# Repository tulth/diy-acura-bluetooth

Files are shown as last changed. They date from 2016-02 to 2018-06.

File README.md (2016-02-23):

# diy-acura-bluetooth
Overview
====================
My DIY project to understand, communicate, and add bluetooth with a 1999 Acura RL bose head unit

Cloning
====================
Be sure to include 

    --recursive 
  
during the git clone to get the submodules!

If you missed this, and do not want to reclone, do the following:

    git submodule update --init --recursive

Building
====================
Build platform:
Arch linux 
with community package: arm-none-eabi-gcc 5.3.0-1
with community package: arm-none-eabi-newlib
with package: python

Desktop shared library
------------
    cd target_desktop
    ./make.sh

Teensy3 embedded executables
------------
    cd target_teensy3
    ./make.sh

Loading
====================
To load you will need this arch linux AUR: teensy-loader-cli

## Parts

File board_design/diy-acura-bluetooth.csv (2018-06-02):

Reference | Value | Footprint | Datasheet | MFN | MFP
P1 | MBUS_CONN | diy-acura-bluetooth:mbus_conn |  | Sullins | PRPC040SBAN-M71RC
P2 | CONN_01X03 | Pin_Headers:Pin_Header_Straight_1x03 |  | Sullins | PRPC040SAAN-RC
U1 | TLV2362 | Housings_DIP:DIP-8_W7.62mm_LongPads |  | Texas Instruments | TLV2362IP
R2 | 100K | Resistors_ThroughHole:Resistor_Horizontal_RM10mm |  | Yageo | MFR-25FBF52-100K
R1 | 100K | Resistors_ThroughHole:Resistor_Horizontal_RM10mm |  | Yageo | MFR-25FBF52-100K
R7 | 20K | Resistors_ThroughHole:Resistor_Horizontal_RM10mm |  | Yageo | MFR-25FBF52-20K
R8 | 20K | Resistors_ThroughHole:Resistor_Horizontal_RM10mm |  | Yageo | MFR-25FBF52-20K
R3 | 20K | Resistors_ThroughHole:Resistor_Horizontal_RM10mm |  | Yageo | MFR-25FBF52-20K
R4 | 20K | Resistors_ThroughHole:Resistor_Horizontal_RM10mm |  | Yageo | MFR-25FBF52-20K
C2 | 1uF | Capacitors_ThroughHole:C_Rect_L7.5_W6.5_P5 |  | Kemet | R82DC4100AA60K
C1 | 1uF | Capacitors_ThroughHole:C_Rect_L7.5_W6.5_P5 |  | Kemet | R82DC4100AA60K
C5 | 1uF | Capacitors_ThroughHole:C_Rect_L7.5_W6.5_P5 |  | Kemet | R82DC4100AA60K
R9 | 20K | Resistors_ThroughHole:Resistor_Horizontal_RM10mm |  | Yageo | MFR-25FBF52-20K
R5 | 20K | Resistors_ThroughHole:Resistor_Horizontal_RM10mm |  | Yageo | MFR-25FBF52-20K
R6 | 20K | Resistors_ThroughHole:Resistor_Horizontal_RM10mm |  | Yageo | MFR-25FBF52-20K
C4 | 1uF | Capacitors_ThroughHole:C_Rect_L7.5_W6.5_P5 |  | Kemet | R82DC4100AA60K
C3 | 1uF | Capacitors_ThroughHole:C_Rect_L7.5_W6.5_P5 |  | Kemet | R82DC4100AA60K
R10 | 20K | Resistors_ThroughHole:Resistor_Horizontal_RM10mm |  | Yageo | MFR-25FBF52-20K
C9 | 10uF | Capacitors_ThroughHole:C_Radial_D5_L11_P2 |  | Kemet | ESK106M016AC3AA
C10 | 0.1uF | Capacitors_ThroughHole:C_Disc_D6_P5 |  | Vishay | K104K10X7RF5UH5
C7 | 2.7uF | Capacitors_ThroughHole:C_Rect_L27_W9_H17_P23 |  | Panasonic | ECW-FD2W275K
C6 | 2.7uF | Capacitors_ThroughHole:C_Rect_L27_W9_H17_P23 |  | Panasonic | ECW-FD2W275K
U3 | R-78E5.0-0.5 | diy-acura-bluetooth:R-78E5.0-0.5 |  | Recom | R-78E5.0-0.5
D1 | 1N4004 | Diodes_ThroughHole:Diode_DO-41_SOD81_Horizontal_RM10 |  | Diodes Incorporated | 1N4004
Q1 | 2N3904 | TO_SOT_Packages_THT:TO-92_Molded_Wide_Oval |  | On Semiconductor | 2N3904
R11 | 4.75K | Resistors_ThroughHole:Resistor_Horizontal_RM10mm |  | Yageo | MFR-25FBF52-4K75
Q3 | 2N3904 | TO_SOT_Packages_THT:TO-92_Molded_Wide_Oval |  | On Semiconductor | 2N3904
R14 | 4.75K | Resistors_ThroughHole:Resistor_Horizontal_RM10mm |  | Yageo | MFR-25FBF52-4K75
C11 | 100uF/10V | Capacitors_ThroughHole:C_Radial_D5_L11_P2 |  | Panasonic | ECA-1AM101
U2 | AS393P-E1 | Housings_DIP:DIP-8_W7.62mm_LongPads |  | Diodes Incorporated | AS393P-E1
R13 | 47.5K | Resistors_ThroughHole:Resistor_Horizontal_RM10mm |  | Yageo | MFR-25FBF52-47K5
R15 | 47.5K | Resistors_ThroughHole:Resistor_Horizontal_RM10mm |  | Yageo | MFR-25FBF52-47K5
R12 | 20K | Resistors_ThroughHole:Resistor_Horizontal_RM10mm |  | Yageo | MFR-25FBF52-20K
Q2 | IRFU9024NPBF | diy-acura-bluetooth:TO-251AA-TPAD |  | International Rectifier | IRFU9024NPBF
Q4 | 2N3904 | TO_SOT_Packages_THT:TO-92_Molded_Wide_Oval |  | On Semiconductor | 2N3904
R17 | 47.5K | Resistors_ThroughHole:Resistor_Horizontal_RM10mm |  | Yageo | MFR-25FBF52-47K5
R18 | 47.5K | Resistors_ThroughHole:Resistor_Horizontal_RM10mm |  | Yageo | MFR-25FBF52-47K5
R16 | 47.5K | Resistors_ThroughHole:Resistor_Horizontal_RM10mm |  | Yageo | MFR-25FBF52-47K5
U4 | TEENSY-3.2 | diy-acura-bluetooth:Teensy-3.1 |  | Sparkfun | DEV-13736
U5 | RN-52-BREAKOUT | diy-acura-bluetooth:RN-52-BREAKOUT |  | Sparkfun | WRL-12849

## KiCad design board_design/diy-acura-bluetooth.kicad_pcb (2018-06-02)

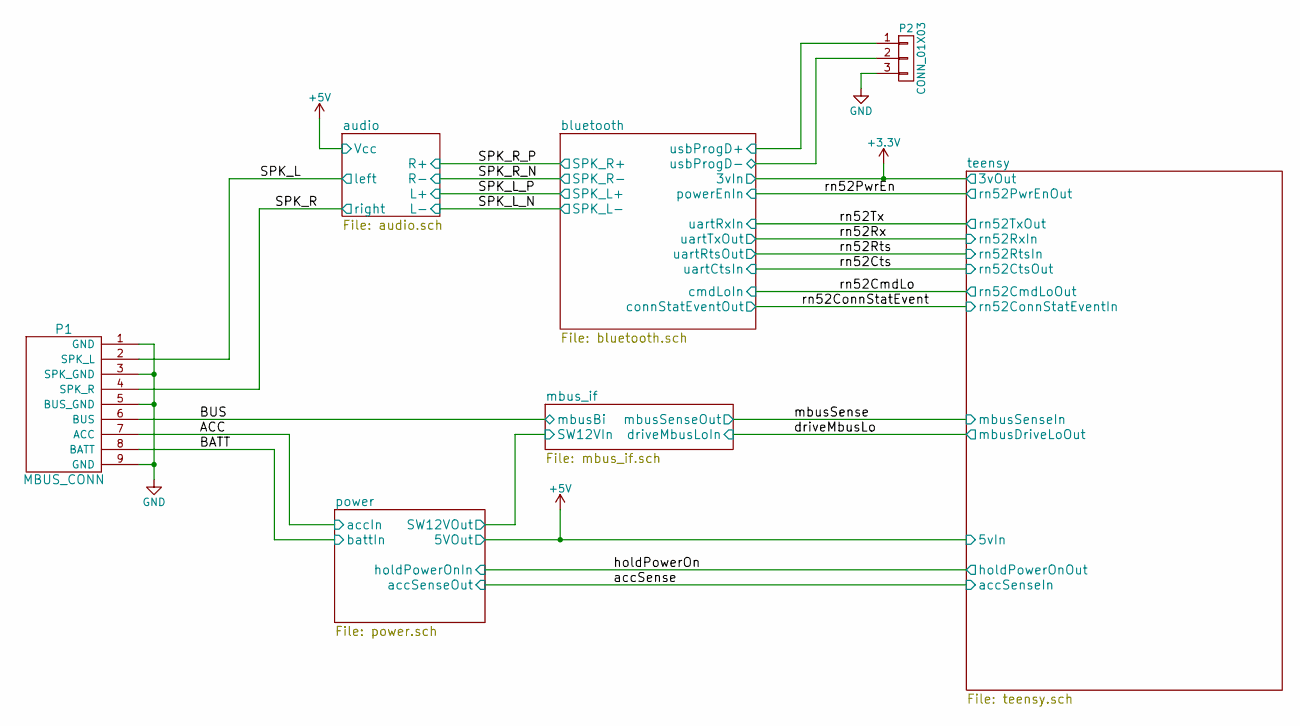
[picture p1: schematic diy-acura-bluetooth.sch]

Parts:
P1: MBUS_CONN; mbus_conn
P2: CONN_01X03; Pin_Header_Straight_1x03

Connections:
/audio/left: P1.2 (SPK_L); also elsewhere on the board
/audio/right: P1.4 (SPK_R); also elsewhere on the board
/bluetooth/usbProgD+: P2.1; also elsewhere on the board
/bluetooth/usbProgD-: P2.2; also elsewhere on the board
/mbus_if/mbusBi: P1.6 (BUS); also elsewhere on the board
/power/accIn: P1.7 (ACC); also elsewhere on the board
/power/battIn: P1.8 (BATT); also elsewhere on the board
GND: P1.1 (GND), P1.3 (SPK_GND), P1.5 (BUS_GND), P1.9 (GND), P2.3; also elsewhere on the board

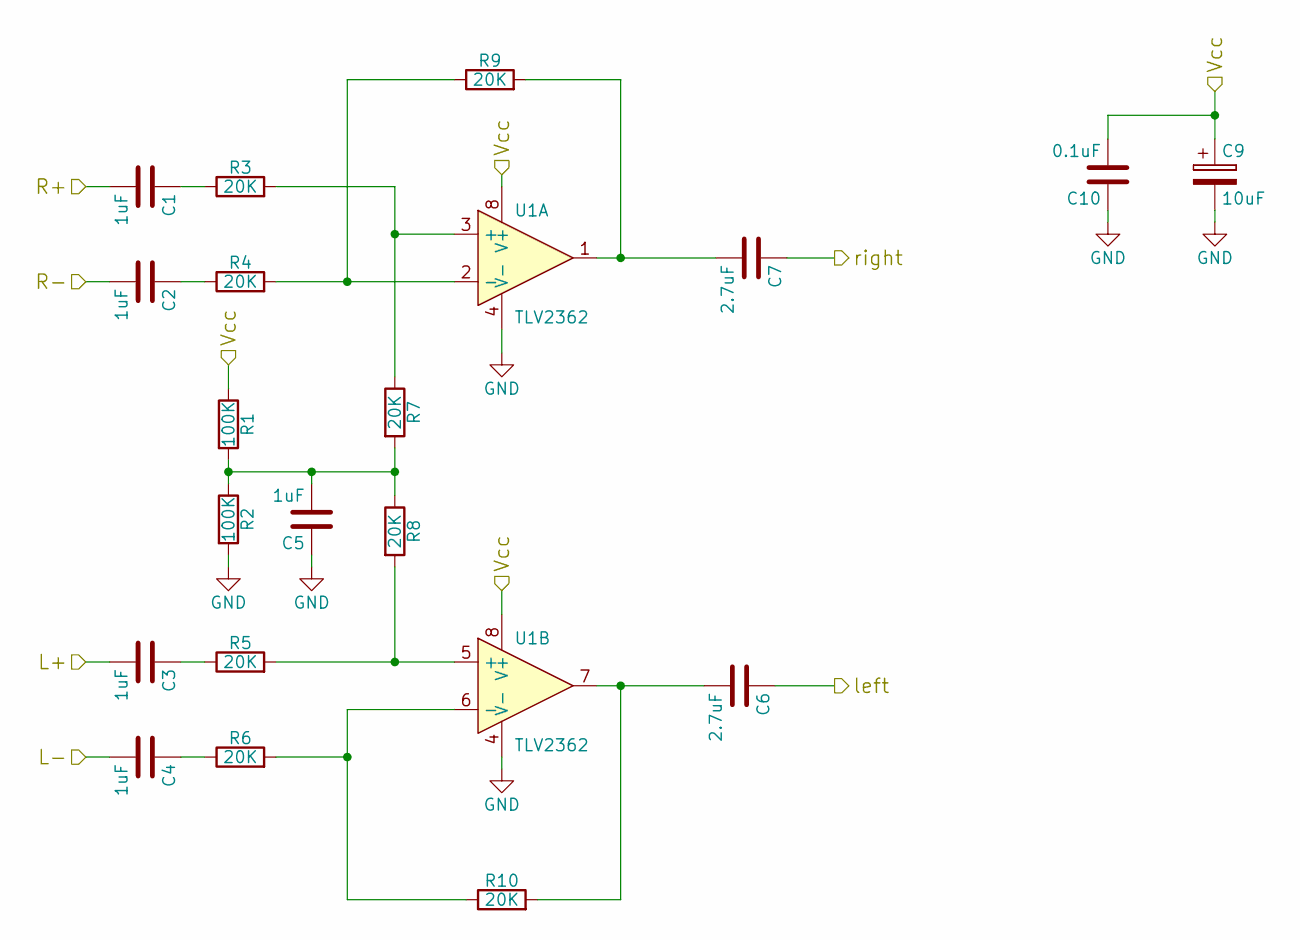
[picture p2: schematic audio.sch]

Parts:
C1, C2, C3, C4, C5: 1uF; C_Rect_L7.5_W6.5_P5
C6, C7: 2.7uF; C_Rect_L27_W9_H17_P23
C9: 10uF; C_Radial_D5_L11_P2
C10: 0.1uF; C_Disc_D6_P5
R1, R2: 100K; Resistor_Horizontal_RM10mm
R3, R4, R5, R6, R7, R8, R9, R10: 20K; Resistor_Horizontal_RM10mm
U1: TLV2362; DIP-8_W7.62mm_LongPads

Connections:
+5V: C9.1, C10.2, R1.1, U1.8 (V+); also elsewhere on the board
/audio/L+: C3.2; also elsewhere on the board
/audio/L-: C4.2; also elsewhere on the board
/audio/R+: C1.2; also elsewhere on the board
/audio/R-: C2.2; also elsewhere on the board
/audio/left: C6.1; also elsewhere on the board
/audio/right: C7.1; also elsewhere on the board
GND: C5.1, C9.2, C10.1, R2.2, U1.4 (V-); also elsewhere on the board
unnamed: C1.1, R3.1
unnamed: C2.1, R4.1
unnamed: C3.1, R5.1
unnamed: C4.1, R6.1
unnamed: C5.2, R1.2, R2.1, R7.2, R8.1
unnamed: C6.2, R10.2, U1.7
unnamed: C7.2, R9.2, U1.1
unnamed: R3.2, R7.1, U1.3 (+)
unnamed: R4.2, R9.1, U1.2 (-)
unnamed: R5.2, R8.2, U1.5 (+)
unnamed: R6.2, R10.1, U1.6 (-)

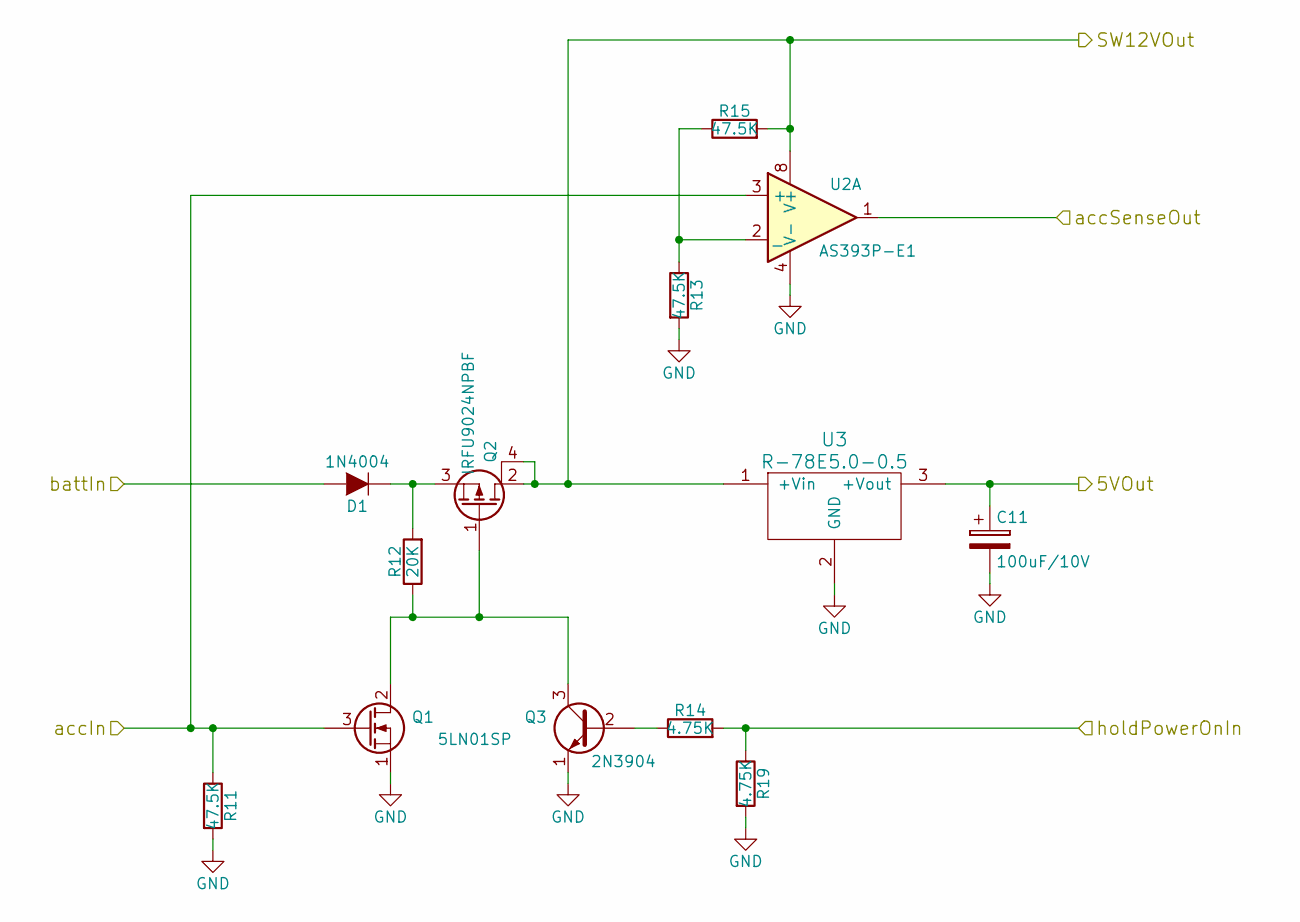
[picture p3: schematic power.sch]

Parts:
C11: 100uF/10V; C_Radial_D5_L11_P2
D1: 1N4004; Diode_DO-41_SOD81_Horizontal_RM10
Q1: 5LN01SP; TO-92_Molded_Wide_Oval
Q2: IRFU9024NPBF; TO-251AA-TPAD
Q3: 2N3904; TO-92_Molded_Wide_Oval
R11, R13, R15: 47.5K; Resistor_Horizontal_RM10mm
R12: 20K; Resistor_Horizontal_RM10mm
R14, R19: 4.75K; Resistor_Horizontal_RM10mm
U2: AS393P-E1; DIP-8_W7.62mm_LongPads
U3: R-78E5.0-0.5

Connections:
+5V: C11.1, U3.3 (+Vout); also elsewhere on the board
/mbus_if/SW12VIn: Q2.2 (D), Q2.4 (D), R15.2, U2.8 (V+), U3.1 (+Vin); also elsewhere on the board
/power/accIn: Q1.3 (G), R11.1, U2.3 (+); also elsewhere on the board
/power/battIn: D1.2 (A); also elsewhere on the board
/power/holdPowerOnIn: R14.2, R19.1; also elsewhere on the board
/teensy/accSenseIn: U2.1; also elsewhere on the board
GND: C11.2, Q1.1 (S), Q3.1 (E), R11.2, R13.2, R19.2, U2.4 (V-), U3.2 (GND); also elsewhere on the board
unnamed: D1.1 (K), Q2.3 (S), R12.2
unnamed: Q1.2 (D), Q2.1 (G), Q3.3 (C), R12.1
unnamed: Q3.2 (B), R14.1
unnamed: R13.1, R15.1, U2.2 (_)

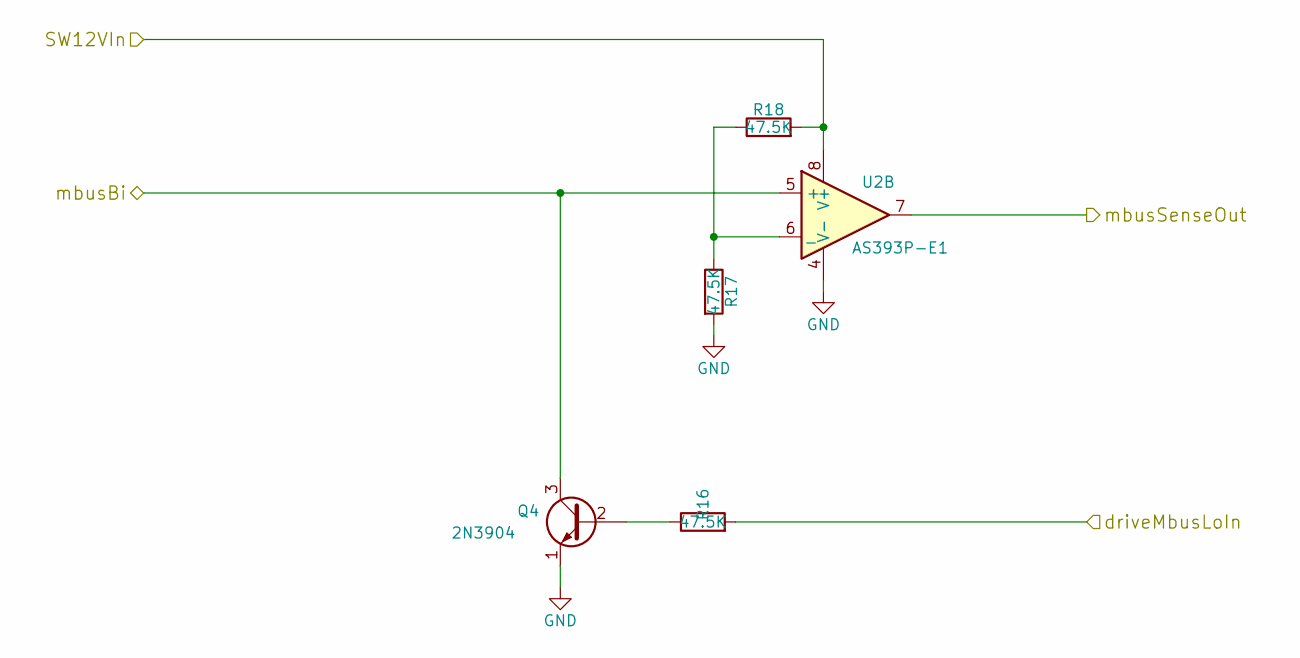
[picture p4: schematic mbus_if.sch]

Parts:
Q4: 2N3904; TO-92_Molded_Wide_Oval
R16, R17, R18: 47.5K; Resistor_Horizontal_RM10mm
U2: AS393P-E1; DIP-8_W7.62mm_LongPads

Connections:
/mbus_if/SW12VIn: R18.2, U2.8 (V+); also elsewhere on the board
/mbus_if/driveMbusLoIn: R16.2; also elsewhere on the board
/mbus_if/mbusBi: Q4.3 (C), U2.5 (+); also elsewhere on the board
/teensy/mbusSenseIn: U2.7; also elsewhere on the board
GND: Q4.1 (E), R17.2, U2.4 (V-); also elsewhere on the board
unnamed: Q4.2 (B), R16.1
unnamed: R17.1, R18.1, U2.6 (_)

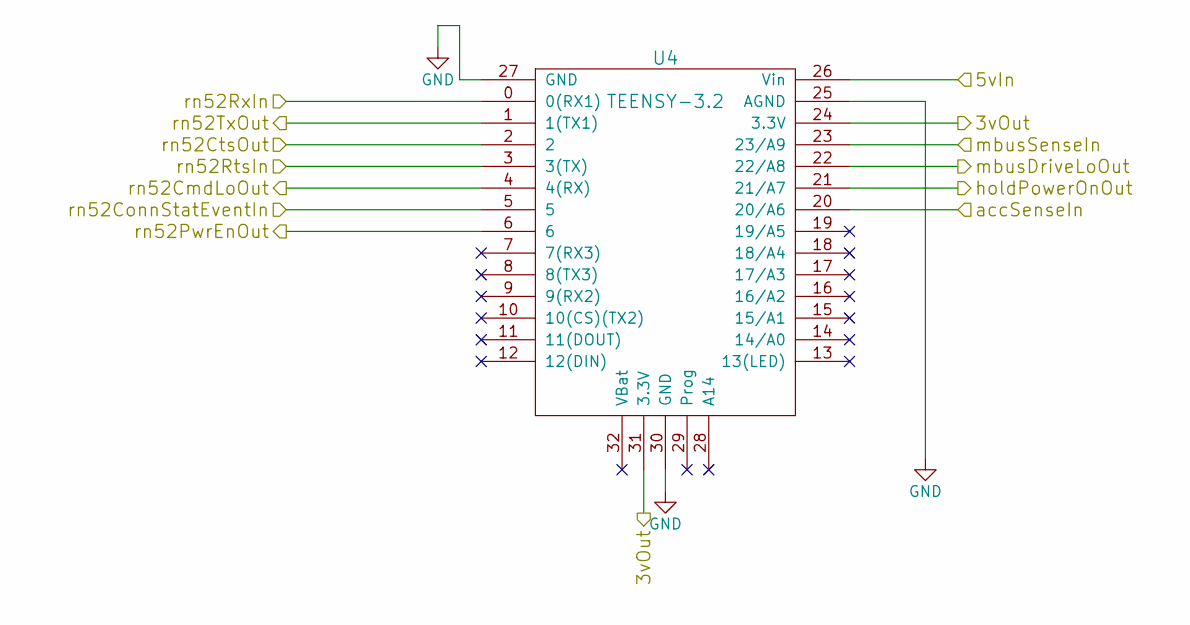
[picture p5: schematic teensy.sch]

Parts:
U4: TEENSY-3.2; Teensy-3.1

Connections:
+3V3: U4.24 (3.3V), U4.31 (3.3V); also elsewhere on the board
+5V: U4.26 (Vin); also elsewhere on the board
/bluetooth/cmdLoIn: U4.4 (4(RX)); also elsewhere on the board
/bluetooth/connStatEventOut: U4.5; also elsewhere on the board
/bluetooth/powerEnIn: U4.6; also elsewhere on the board
/mbus_if/driveMbusLoIn: U4.22 (22/A8); also elsewhere on the board
/power/holdPowerOnIn: U4.21 (21/A7); also elsewhere on the board
/teensy/accSenseIn: U4.20 (20/A6); also elsewhere on the board
/teensy/mbusSenseIn: U4.23 (23/A9); also elsewhere on the board
/teensy/rn52CtsOut: U4.2; also elsewhere on the board
/teensy/rn52RtsIn: U4.3 (3(TX)); also elsewhere on the board
/teensy/rn52RxIn: U4.0 (0(RX1)); also elsewhere on the board
/teensy/rn52TxOut: U4.1 (1(TX1)); also elsewhere on the board
GND: U4.25 (AGND), U4.27 (GND), U4.30 (GND); also elsewhere on the board

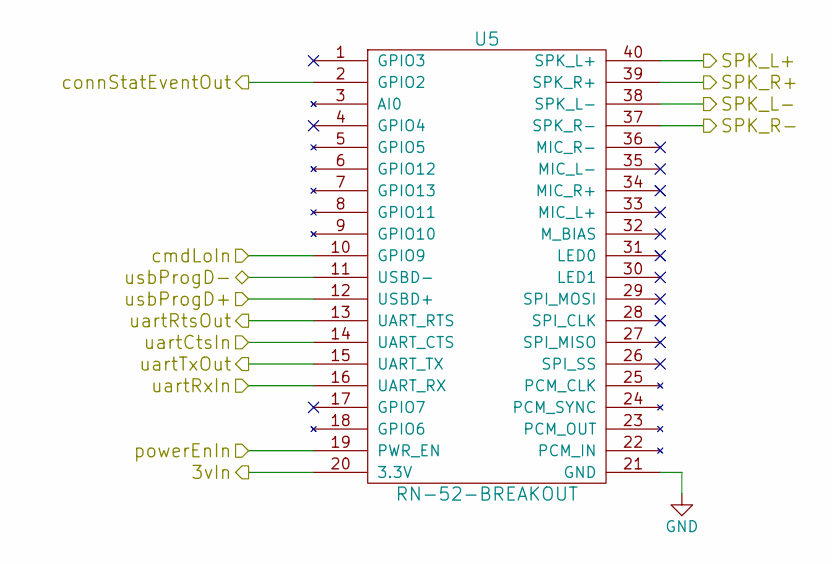
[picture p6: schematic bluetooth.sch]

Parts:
U5: RN-52-BREAKOUT

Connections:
+3V3: U5.20 (3.3V); also elsewhere on the board
/audio/L+: U5.40 (SPK_L+); also elsewhere on the board
/audio/L-: U5.38 (SPK_L-); also elsewhere on the board
/audio/R+: U5.39 (SPK_R+); also elsewhere on the board
/audio/R-: U5.37 (SPK_R-); also elsewhere on the board
/bluetooth/cmdLoIn: U5.10 (GPIO9); also elsewhere on the board
/bluetooth/connStatEventOut: U5.2 (GPIO2); also elsewhere on the board
/bluetooth/powerEnIn: U5.19 (PWR_EN); also elsewhere on the board
/bluetooth/usbProgD+: U5.12 (USBD+); also elsewhere on the board
/bluetooth/usbProgD-: U5.11 (USBD-); also elsewhere on the board
/teensy/rn52CtsOut: U5.14 (UART_CTS); also elsewhere on the board
/teensy/rn52RtsIn: U5.13 (UART_RTS); also elsewhere on the board
/teensy/rn52RxIn: U5.15 (UART_TX); also elsewhere on the board
/teensy/rn52TxOut: U5.16 (UART_RX); also elsewhere on the board
GND: U5.21 (GND); also elsewhere on the board

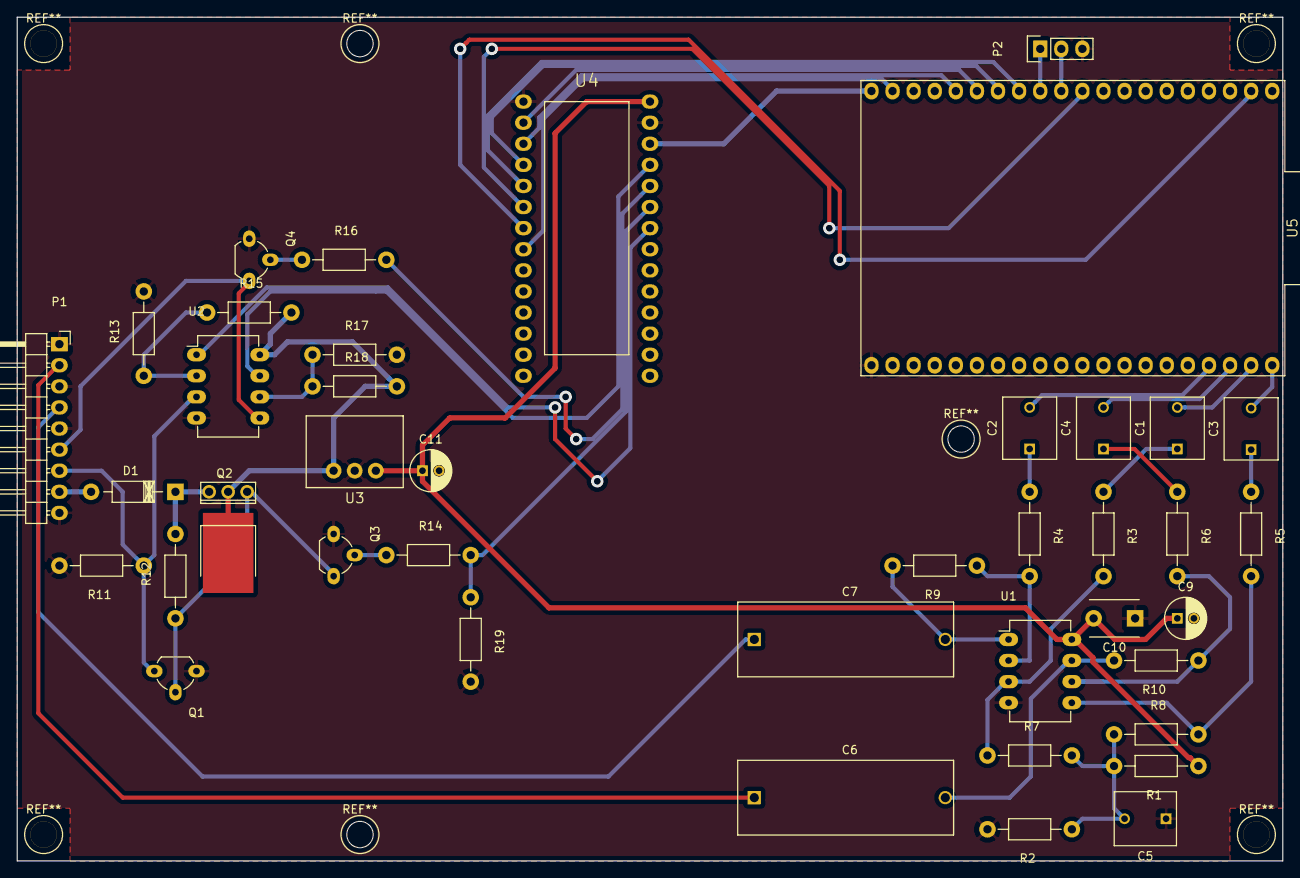
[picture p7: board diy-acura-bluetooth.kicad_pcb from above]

Board: 2 copper layers, 152.4 x 101.6 mm, 41 parts (0 on the bottom side), 43 nets.

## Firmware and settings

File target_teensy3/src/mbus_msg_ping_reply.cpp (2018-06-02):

#include <stdbool.h>
#include <stdint.h>
#include <WProgram.h>
#include <core_pins.h>
#include "mbus_phy.h"
#include "mbus_link.h"

#define BYTE_MEM_SIZE 64
#define MSG_MEM_SIZE 2
#define MSG_STR_SIZE 256

#define PINBIT_LED CORE_PIN13_BITMASK
#define PINBIT_MBUS_SENSE CORE_PIN23_BITMASK
#define PINBIT_MBUS_DRIVE_LO CORE_PIN22_BITMASK

#define USBSERIAL Serial

extern "C" int main(void)
{
  elapsedMillis blinkMilliSecElapsed;
  uint8_t rxByteMem[BYTE_MEM_SIZE];
  uint8_t txByteMem[BYTE_MEM_SIZE];
  uint8_t rxNibble;
  MbusRxMsgStruct rxMsgMem[MSG_MEM_SIZE];
  MbusTxMsgStruct txMsgMem[MSG_MEM_SIZE];
  MbusRxMsgStruct rxMsg;
  MbusPhyStruct mbusPhy;
  MbusLinkStruct mbusLink;
  bool driveMbusPinLo = false;
  bool mbusPhyDirectionUpdated;
  char msgStr[MSG_STR_SIZE];
  int msgStrLen;

  PORTC_PCR5 = PORT_PCR_SRE | PORT_PCR_DSE | PORT_PCR_MUX(1); /* LED */
  PORTC_PCR2 = PORT_PCR_PE  | PORT_PCR_PS  | PORT_PCR_MUX(1); /* MBUS SENSE */
  PORTC_PCR1 = PORT_PCR_SRE | PORT_PCR_DSE | PORT_PCR_MUX(1); /* MBUS DRIVE LO */

  GPIOC_PDDR |= PINBIT_LED;  /* gpio data direction reg, for led bit */
  GPIOC_PDDR |= PINBIT_MBUS_DRIVE_LO;  /* gpio data direction reg, for driveMbusPinLo */
  
  GPIOC_PCOR = PINBIT_LED;  /* set led bit low */
  GPIOC_PCOR = PINBIT_MBUS_DRIVE_LO;  /* don't drive low */

  USBSERIAL.begin(115200);
  blinkMilliSecElapsed = 0;
  mbus_phy_init(&mbusPhy,
                rxByteMem,
                BYTE_MEM_SIZE,
                txByteMem,
                BYTE_MEM_SIZE);
  mbus_phy_rx_enable(&mbusPhy);
  mbus_link_init(&mbusLink,
                 rxMsgMem,
                 MSG_MEM_SIZE * sizeof(MbusRxMsgStruct),
                 txMsgMem,
                 MSG_MEM_SIZE * sizeof(MbusTxMsgStruct),
                 &(mbusPhy.tx.byteFifo));

  while (1) {
    /* blink */
    if (blinkMilliSecElapsed > 1000) {
      GPIOC_PTOR = PINBIT_LED;  /* gpio toggle reg, for led bit */
      blinkMilliSecElapsed = 0;
    }

    /* mbusPhy */
    mbus_phy_update(&mbusPhy,
                    micros(),
                    (GPIOC_PDIR & PINBIT_MBUS_SENSE) != 0,
                    &driveMbusPinLo
                    );
    if (driveMbusPinLo) {
      GPIOC_PSOR = PINBIT_MBUS_DRIVE_LO;  /* drive low, so we drive 1 out; inverted by the drive transistor */
    } else {
      GPIOC_PCOR = PINBIT_MBUS_DRIVE_LO;  /* don't pull low */
    }

    /* mbusPhy->mbusLink */
    if (!mbus_phy_rx_is_empty(&mbusPhy)) {
      rxNibble = mbus_phy_rx_pop(&mbusPhy);
      mbus_link_rx_push_nibble(&mbusLink, rxNibble);
    }

    /* mbusLink */
    mbus_link_update(&mbusLink, mbus_phy_rx_is_busy(&mbusPhy), mbus_phy_tx_is_busy(&mbusPhy), &mbusPhyDirectionUpdated);
    if (mbusPhyDirectionUpdated) {
      if (mbus_link_is_direction_rx(&mbusLink)) {
        mbus_phy_tx_disable(&mbusPhy);
        mbus_phy_rx_enable(&mbusPhy);
      } else {
        mbus_phy_rx_disable(&mbusPhy);
        mbus_phy_tx_enable(&mbusPhy);
      }
    }
    /* print mbusLink rx msg if one is available */
    if (!mbus_link_rx_is_empty(&mbusLink)) {
      mbus_link_rx_pop(&mbusLink, &rxMsg);
      if ((!rxMsg.errId) && (rxMsg.parsed.directionH2C)) {
        if (rxMsg.parsed.msgType == MSGTYPE_ping) {
          mbus_phy_tx_push(&mbusPhy, 0x9);
          mbus_phy_tx_push(&mbusPhy, 0x8);
          mbus_phy_tx_push(&mbusPhy, 0x2);
          USBSERIAL.println("sent pong");
        }
      }
      msgStrLen = mbus_link_msgToStr(&rxMsg,
                                     msgStr,
                                     MSG_STR_SIZE);
      USBSERIAL.println(msgStr);
    }

    yield();
  }
}

/* int __assert_func(const char *fn, long line) */
void __assert(const char *, int, const char *)
{
  USBSERIAL.println("assert fail! halting!");
  while (1) { ; }
}

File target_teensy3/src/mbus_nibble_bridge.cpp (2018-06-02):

#include <stdbool.h>
#include <stdint.h>
#include <WProgram.h>
#include <core_pins.h>
#include "mbus_phy.h"
#include "mbus_link.h"
#include "app_debug.h"
#define BYTE_MEM_SIZE 64

#define PINBIT_LED CORE_PIN13_BITMASK
#define PINBIT_MBUS_SENSE CORE_PIN23_BITMASK
#define PINBIT_MBUS_DRIVE_LO CORE_PIN22_BITMASK

#define USBSERIAL Serial

extern "C" int main(void)
{
  elapsedMillis blinkMilliSecElapsed;
  uint8_t rxByteMem[BYTE_MEM_SIZE];
  uint8_t txByteMem[BYTE_MEM_SIZE];
  char txCharMem[32];
  uint8_t rxNibble;
  char txChar;
  uint8_t txNib;
  uint8_t txNibQueue[32];
  int txNibQueueIdx;
  bool transmitting = false;
  int txNibQueueLastIdx = 0;
  MbusPhyStruct phy;
  bool driveMbusPinLo = false;

  PORTC_PCR5 = PORT_PCR_SRE | PORT_PCR_DSE | PORT_PCR_MUX(1); /* LED */
  PORTC_PCR2 = PORT_PCR_PE  | PORT_PCR_PS  | PORT_PCR_MUX(1); /* MBUS SENSE */
  PORTC_PCR1 = PORT_PCR_SRE | PORT_PCR_DSE | PORT_PCR_MUX(1); /* MBUS DRIVE LO */

  GPIOC_PDDR |= PINBIT_LED;  /* gpio data direction reg, for led bit */
  GPIOC_PDDR |= PINBIT_MBUS_DRIVE_LO;  /* gpio data direction reg, for driveMbusPinLo */
  GPIOC_PCOR = PINBIT_MBUS_DRIVE_LO;  /* don't drive low */

  GPIOC_PCOR = PINBIT_LED;  /* set led bit low */

  USBSERIAL.begin(115200);
  blinkMilliSecElapsed = 0;
  mbus_phy_init(&phy,
                rxByteMem,
                BYTE_MEM_SIZE,
                txByteMem,
                BYTE_MEM_SIZE);
  mbus_phy_rx_enable(&phy);

  while (1) {
    /* blink */
    if (blinkMilliSecElapsed > 1000) {
      GPIOC_PTOR = PINBIT_LED;  /* gpio toggle reg, for led bit */
      blinkMilliSecElapsed = 0;
    }

    /* phy */
    mbus_phy_update(&phy,
                    micros(),
                    (GPIOC_PDIR & PINBIT_MBUS_SENSE) != 0,
                    &driveMbusPinLo
                    );
    if (driveMbusPinLo) {
      GPIOC_PSOR = PINBIT_MBUS_DRIVE_LO;  /* drive low, so we drive 1 out - inverted by the drive transistor */
    } else {
      GPIOC_PCOR = PINBIT_MBUS_DRIVE_LO;  /* don't pull low */
    }

    if (!mbus_phy_rx_is_empty(&phy)) {
      rxNibble = mbus_phy_rx_pop(&phy);
      if (rxNibble == MBUS_END_MSG_CODE) {
        app_debug_putchar('\r');
        app_debug_putchar('\n');
      } else {
        app_debug_putchar(mbus_phy_rxnibble2ascii(rxNibble));
      }        
    }
    if (USBSERIAL.available()) {
      txChar = USBSERIAL.read();
      txNib = mbus_phy_ascii2txnibble(txChar);
      if (txChar == 0x0d) {  // newlines come in as 0x0D for some reason
        txNib = MBUS_END_MSG_CODE;
      }
      // app_debug_printf("beep %d %d\r\n", txChar, txNib);
      if (txNib & 0x80) {  // misbit set if bad nibble
        ; // do nothing
      } else {
        txNibQueue[txNibQueueLastIdx] = txNib;
        txNibQueueLastIdx++;
        if (txNib == MBUS_END_MSG_CODE) {
          if (!mbus_phy_rx_is_busy(&phy) and !transmitting) {
            transmitting = true;            
            mbus_phy_tx_enable(&phy);
            for (txNibQueueIdx=0; txNibQueueIdx < txNibQueueLastIdx; txNibQueueIdx++) {
              mbus_phy_tx_push(&phy, txNibQueue[txNibQueueIdx]);
            }
            for (txNibQueueIdx=0; txNibQueueIdx < txNibQueueLastIdx; txNibQueueIdx++) {
              app_debug_printf("%x  ", txNibQueue[txNibQueueIdx]);
            }
            app_debug_print("\r\n");
            txNibQueueLastIdx = 0;
          }
        }
      }
    }
    if (transmitting) {
      if (!mbus_phy_tx_is_busy(&phy)) {
        transmitting = false;
        mbus_phy_tx_disable(&phy);
      }
    }
    yield();
  }
}

/* int __assert_func(const char *fn, long line) */
void __assert(const char *, int, const char *)
{
  USBSERIAL.println("assert fail! halting!");
  while (1) { ; }
}

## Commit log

2016-02-23 Now referencing the teensy3 core git repo as a submodule.
2016-02-23 Turn up the compile warning error reporting on internal code. Update teensy3 submodule code to not use these strict flags because it fails these.Turn up the compile warning error reporting on interna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
2016-02-23 add comment on arm newlib dependency
2016-02-23 teensy3 cmake: remove duplication by looping over top targets
2016-02-25 Added nibble printing for MBUS error codes.
2016-02-26 reworking embedded exes to new naming plan
    [mbus_nibble_sniffer.cpp, mbus_toggle_sniffer.cpp]
2016-02-27 Added embedded executables: bt_bridge (bluetooth), mbus_msg_sniffer, mbus_nibble_bridge, mbus_toggle_bridge. Reworked mbus_link to be its own layer with fifo's with hooks for TX capability (though TX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
    [bt_bridge.cpp, mbus_msg_sniffer.cpp, mbus_nibble_bridge.cpp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]
2016-03-06 fix: circ buf nonmalloc init should specify bufsize, not capacity
2016-03-06 extra printing on nibble array struct
2016-03-06 add noshuttle bit field. fix python printing issue on pong msg.
2016-03-11 Add helpful teensy programmer script
2016-03-11 fix: mbus tx switches back to rx before the last tx nibble is finished
    [mbus_msg_ping_reply.cpp]
2016-03-11 fix: incorrect bufsize for link msg bufs. fix: nibble sniffer did not enable rx.
    [mbus_msg_ping_reply.cpp, mbus_msg_sniffer.cpp, mbus_nibble_sniffer.cpp]
2016-03-11 add commented out mbus drive pin capability
2016-03-13 fix port setup assignment to not use |=. init driveMbusPinLo as false. Drive portc1 high when driveMbusPinLo is 1.
    [mbus_msg_ping_reply.cpp, mbus_msg_sniffer.cpp, mbus_nibble_bridge.cpp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]
2016-03-13 Renamed circular_buffer to fifo. updated python scripts to have/use MbusTxMsgStruct. Fixed python MbusRawNibbleListStructList to use MbusRawNibbleListList
    [mbus_msg_ping_reply.cpp]
2016-03-13 Cleanup pass: make all teensy main progs consistent.
2016-03-15 garage fixes: always busy tx phy bug, link:bad packed tx transmission and do not send pending tx the queue is empty. Disable rn 52 section for now.
    [app_demo.cpp]
2016-03-16 new debug printing. RN52 enabled and prints state changes.
2016-03-18 app demo toggle sniffer main, debug print defaults to no newline now, added defines to enable module level debugging, more debugging code
2016-03-18 fix rx->tx checksum bug: caused by rx enable resetting rx back to idle mode
    [app_demo.cpp, app_demo_toggle_sniffer.cpp]
2016-03-20 many fixes. now music plays and next/previous work. added fifo id for fifo debug
    [app_demo.cpp]
2016-03-29 adding the work in progress board design to git
    [audio.sch, bluetooth.sch, diy-acura-bluetooth.csv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]
2017-01-21 WIP commit before redoing layout for 0.5mm bit and before adding microphone port.
    [audio.sch, bluetooth.sch, diy-acura-bluetooth.kicad_pcb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]
2018-03-29 add build for teensy lc
2018-03-30 teensy3 is slightly different than teensy lc pins start using core pins bitmask
2018-03-30 teensy3 is slightly different than teensy lc pins pt 2 start using core pins bitmask
2018-03-30 switch all pin pits to use core pins
2018-03-30 attempt cmd lo pin fix on app_demo and bt bridge
    [app_demo.cpp, bt_bridge.cpp]
2018-03-31 reconnect bt on power on and no rn52 debug, mostly works sometimes the head unit still fails to connect sometime the bt seems to be disabled
2019-05-24 add rn52 debug print on timeout
2019-05-24 add reboot on switch disk4
    [app_demo.cpp]
2019-06-09 change reboot to just reboot rn52. reboot teensy did not seem to work
    [app_demo.cpp]
